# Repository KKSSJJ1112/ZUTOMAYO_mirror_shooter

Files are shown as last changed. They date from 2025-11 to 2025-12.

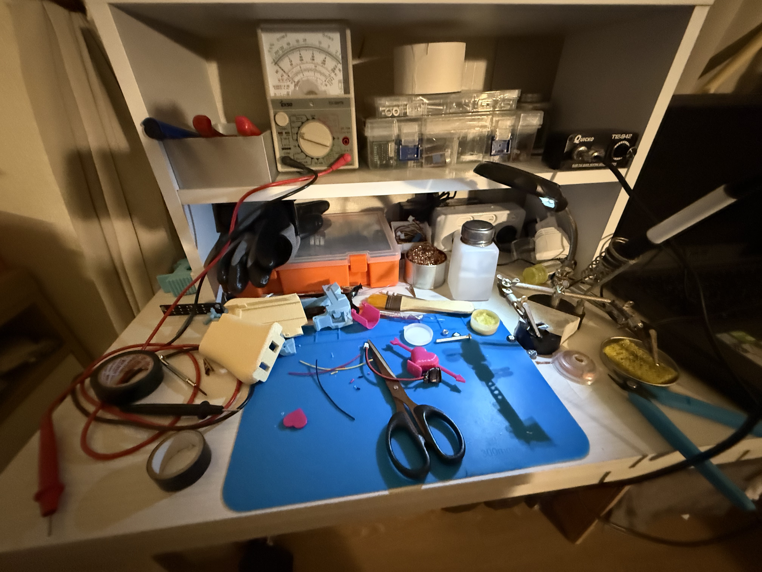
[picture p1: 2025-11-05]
사진/14.jpg

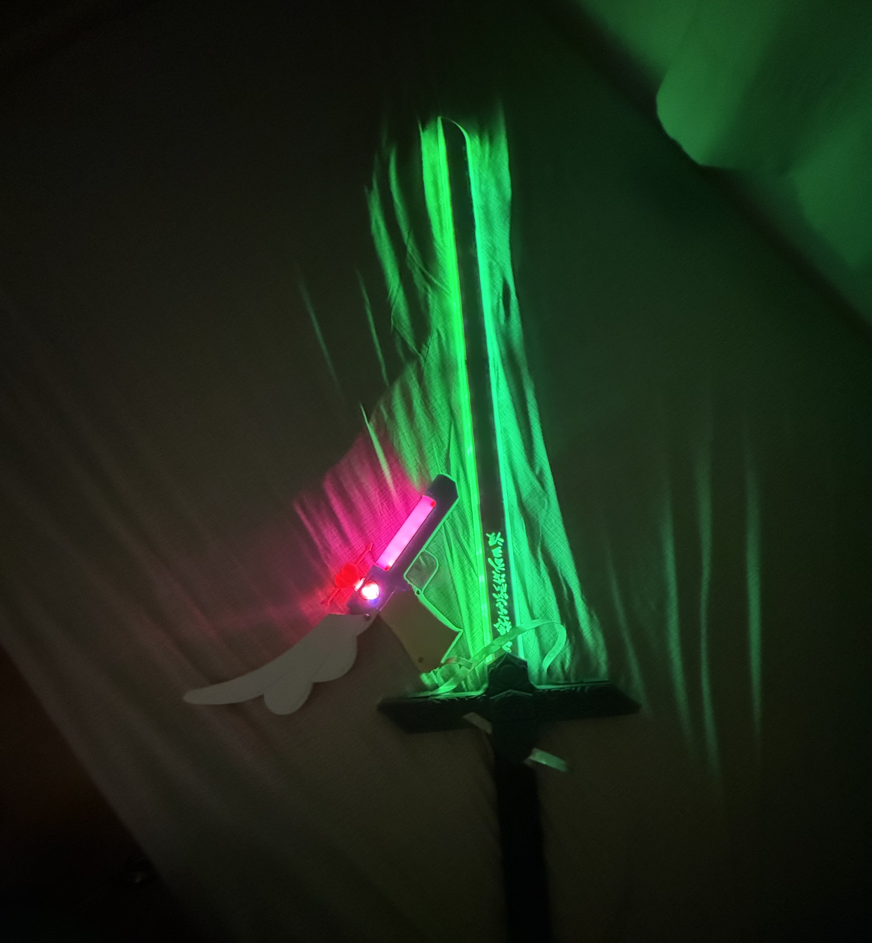
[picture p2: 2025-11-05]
사진/15.jpg

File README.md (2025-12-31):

ffa

# 🔫 Mirror Shooter / ミラーシューター / 미러슈터

> **Language / 言語 / 언어**: [English](#english) | [日本語](#日本語) | [한국어](#한국어)

---

## English

### ZUTOMAYO Mirror Shooter (DIY Replica)

A handmade replica of the mirror shooter prop featured in music videos and live performances by the Japanese J-pop band **ZUTOMAYO** (ずっと真夜中でいいのに。).

This pistol-shaped prop features LED illumination and a laser emitter at the muzzle.

### Features

- 3300mAh lithium-ion battery system
- Modular case design (assembly/disassembly capable)
- 3D printed enclosure
- Reprogrammable (color customization, etc.)
- Physical trigger switch for laser on/off mode toggle

### Components

| Part | Specification |
|---|---|
| PCB | Custom designed in KiCad, hand-soldered |
| MCU | ESP32-C3 Super Mini |
| LED Strip | NeoPixel (WS2812B) |
| Slide LED Ring | NeoPixel |
| Battery | Samsung SDI 18650 Li-ion cell |

### Project Structure

```
├── mirror/              # ESP32 PlatformIO project files
├── mirror_Shooter_v2/   # KiCad project files
└── mirrorshooter_stl/   # 3D printable STL files
```

### [Photos ↓](#gallery)

---

## 日本語

### ずっと真夜中でいいのに。ミラーシューター（自作レプリカ）

日本のJ-popバンド「**ずっと真夜中でいいのに。**」（以下、ずとまよ）のMVやライブに登場するミラーシューターを自作しました。

拳銃型の小道具で、LEDによる発光と銃口部分からのレーザー照射が特徴です。

### 主な特徴

- 3300mAhリチウムイオンバッテリーシステム
- 組み立て・分解可能なケース構造
- 3Dプリント製ケース
- 再プログラミング可能（カラー変更など）
- トリガーの物理プッシュスイッチによるレーザーON/OFFモード切替

### 構成部品

| 部品 | 仕様 |
|---|---|
| PCB | KiCadで設計、手はんだ実装 |
| MCU | ESP32-C3 Super Mini |
| LEDストリップ | NeoPixel（WS2812B） |
| スライド背面LEDリング | NeoPixel |
| バッテリー | Samsung SDI 18650 リチウムイオンセル |

### プロジェクト構成

```
├── mirror/              # ESP32 PlatformIOプロジェクトファイル
├── mirror_Shooter_v2/   # KiCadプロジェクトファイル
└── mirrorshooter_stl/   # 3Dプリント用STLファイル
```

### [写真 ↓](#gallery)

---

## 한국어

### 계속 한밤중이면 좋을텐데 미러슈터 (자작)

일본의 J-pop 밴드 **계속 한밤중이면 좋을텐데**(ずっと真夜中でいいのに。, 이하 즈토마요)의 MV 및 라이브에 등장하는 미러슈터를 제작했습니다.

권총형 소품으로, LED를 통한 발광과 총구 부분에서의 레이저가 특징입니다.

### 주요 특징

- 3300mAh 리튬 이온 배터리 시스템
- 조립 및 분해 가능한 케이스 구조
- 3D 프린팅 케이스
- 추후 재프로그래밍 가능 (색상 변경 등)
- 트리거의 물리 푸시 스위치를 통한 레이저 ON/OFF 모드 변경

### 구성 부품

| 부품 | 사양 |
|---|---|
| PCB | KiCad 설계, 핸드 솔더링 |
| MCU | ESP32-C3 Super Mini |
| LED 스트립 | NeoPixel (WS2812B) |
| 슬라이드 후면 LED 링 | NeoPixel |
| 배터리 | Samsung SDI 18650 리튬이온 셀 |

### 프로젝트 구조

```
├── mirror/              # ESP32 PlatformIO 프로젝트 파일
├── mirror_Shooter_v2/   # KiCad 프로젝트 파일
└── mirrorshooter_stl/   # 3D 프린팅용 STL 파일
```

### [사진 ↓](#gallery)

---

## Gallery

KakaoTalk_20251231_225942691_01

KakaoTalk_20251231_225942691_02







KakaoTalk_20251231_225942691



<!-- 이미지를 여기에 추가하세요 / Add images here / 画像をここに追加 -->

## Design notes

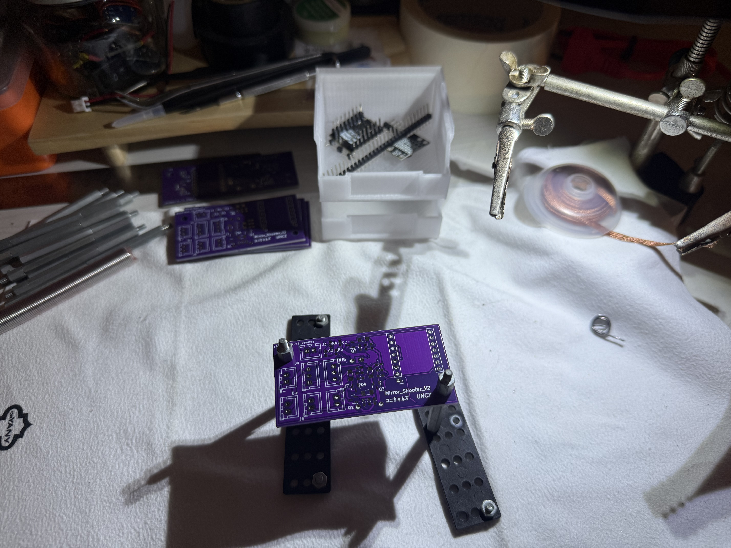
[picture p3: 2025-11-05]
사진/KakaoTalk_20250901_193324154_02.jpg

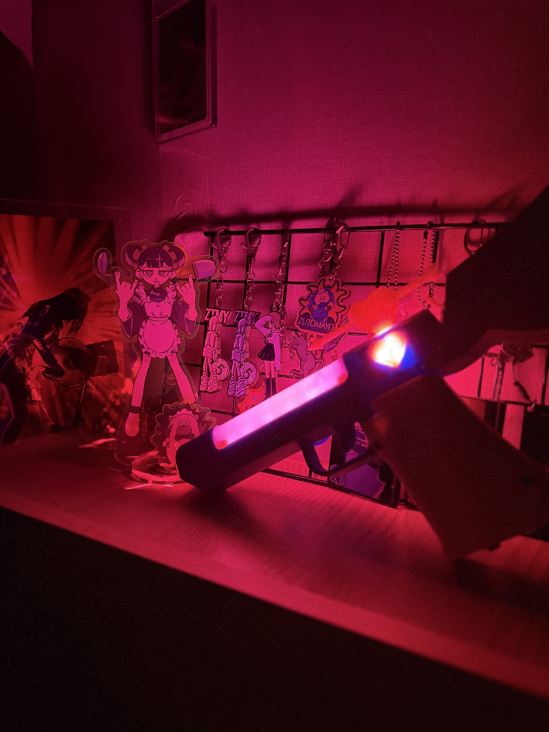
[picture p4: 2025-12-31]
사진/KakaoTalk_20251231_225942691_01.jpg

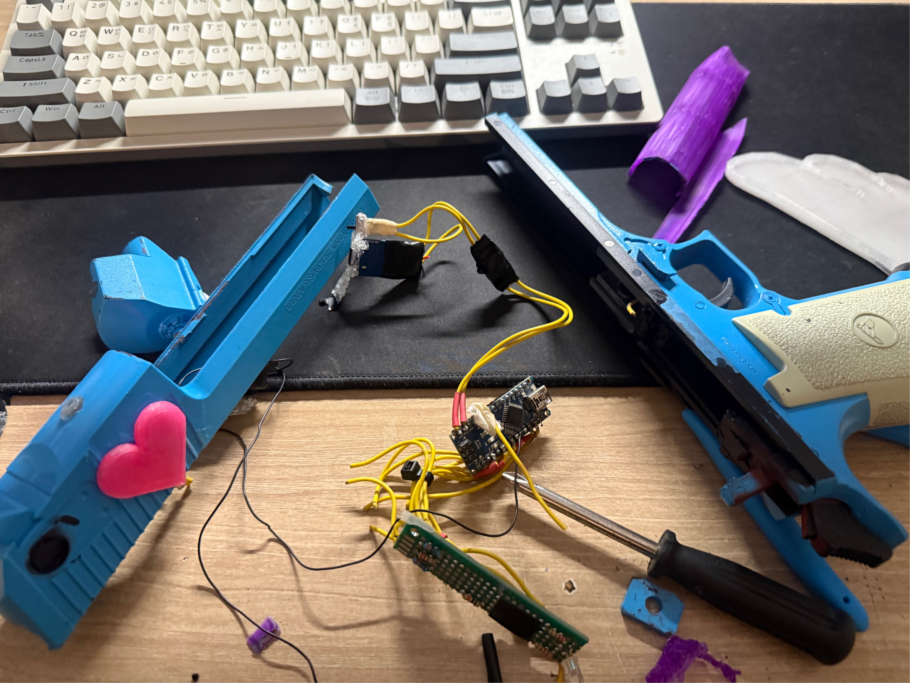
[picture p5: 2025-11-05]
사진/KakaoTalk_20250901_195342667_01.jpg

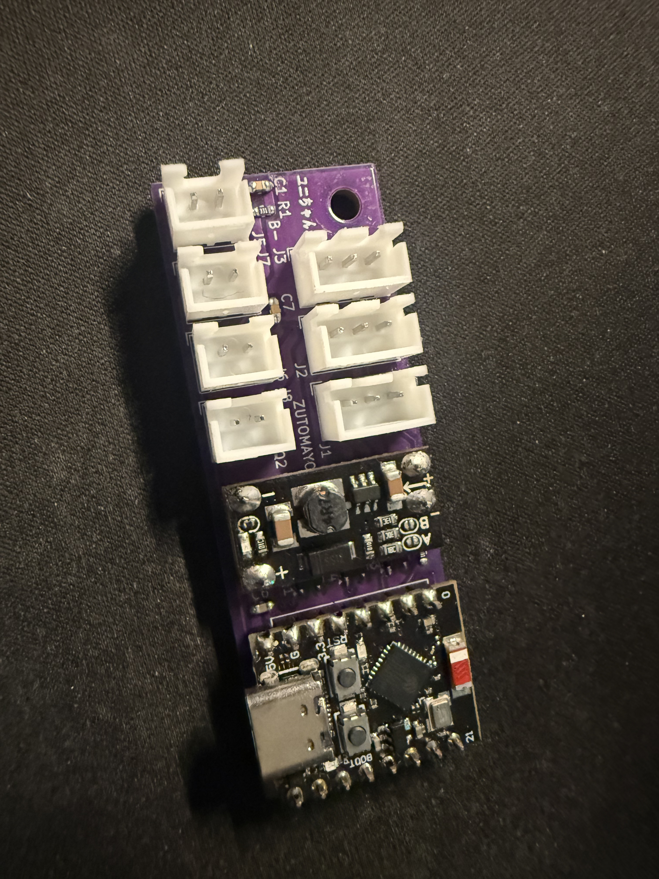
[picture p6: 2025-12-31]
사진/KakaoTalk_20251231_225942691.jpg

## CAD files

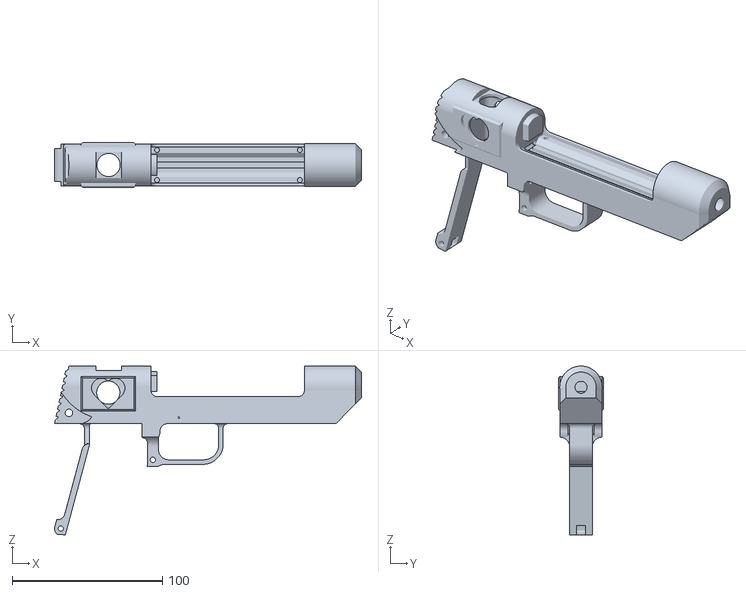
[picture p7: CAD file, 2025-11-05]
mirrorshooter_stl/____final/blue/main-frame.stl
204.2 x 30.0 x 112.3

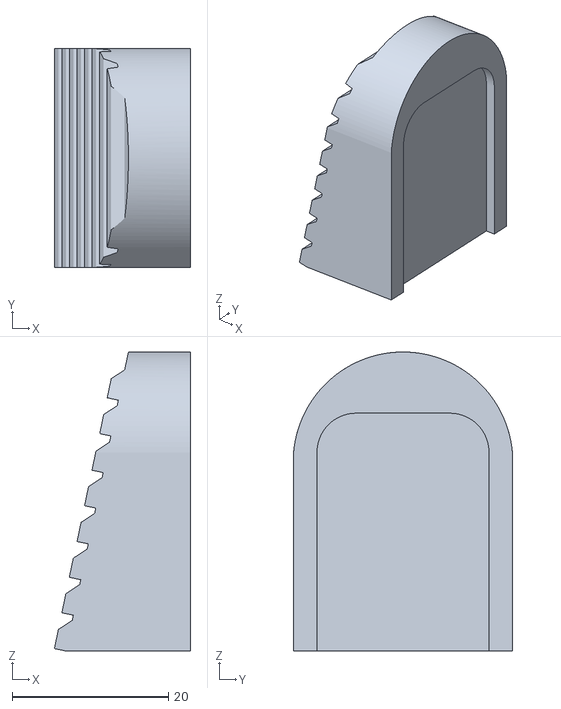
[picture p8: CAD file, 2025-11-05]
mirrorshooter_stl/test/first_test/ex_test/backside-main-test.stl
17.4 x 28.0 x 38.2

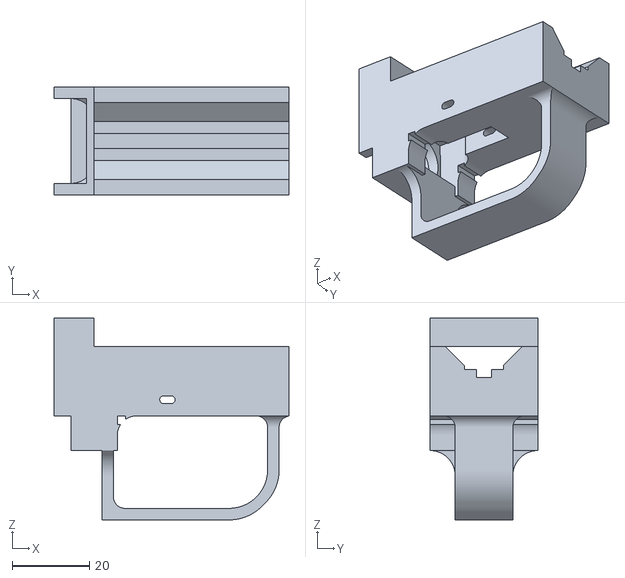
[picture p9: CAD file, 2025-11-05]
mirrorshooter_stl/test/first_test/trigger_test/triger-main-test.stl
61.0 x 28.0 x 52.4

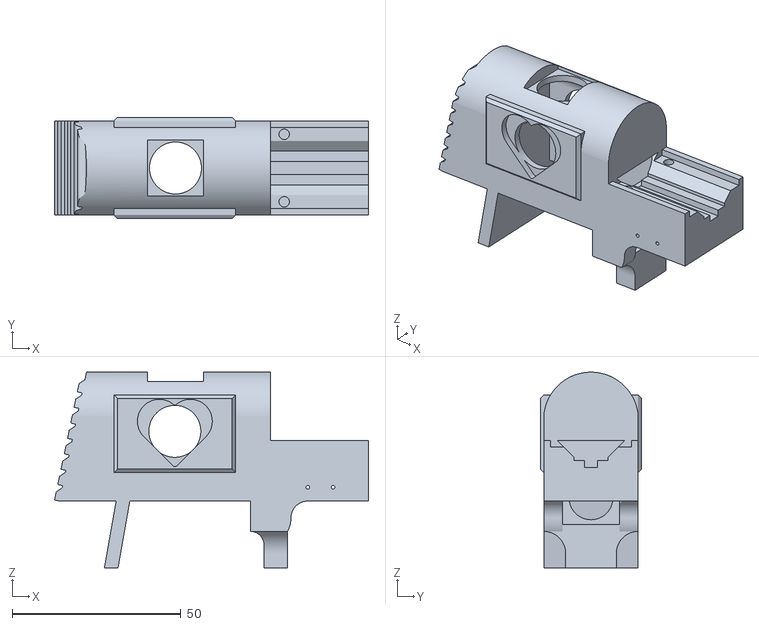
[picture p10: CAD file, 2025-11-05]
mirrorshooter_stl/test/second_test/blue/main frame test.stl
93.1 x 30.0 x 58.1

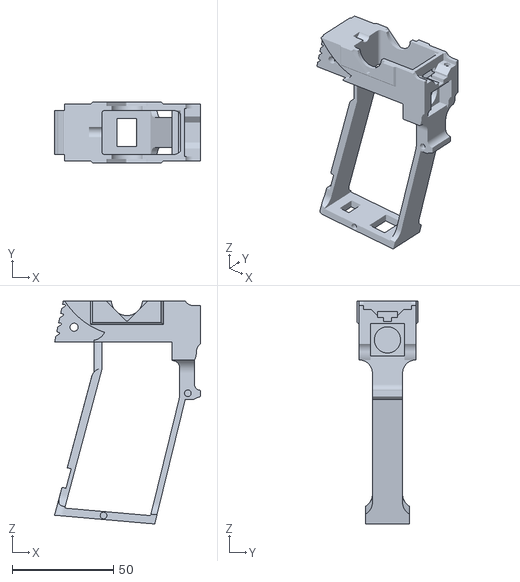
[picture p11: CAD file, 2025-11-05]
mirrorshooter_stl/test/second_test/blue/wing grip test main.stl
72.3 x 30.0 x 110.4

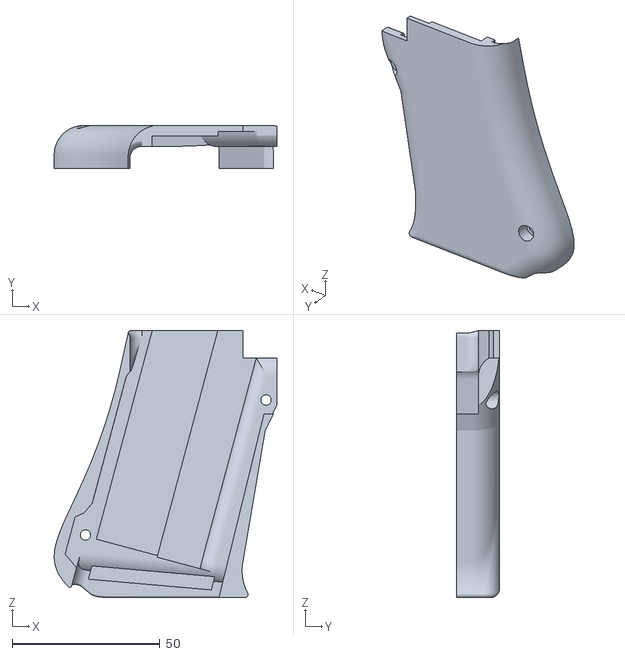
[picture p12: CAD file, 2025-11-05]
mirrorshooter_stl/____final/milk white/grib-l.stl
75.5 x 14.6 x 90.5

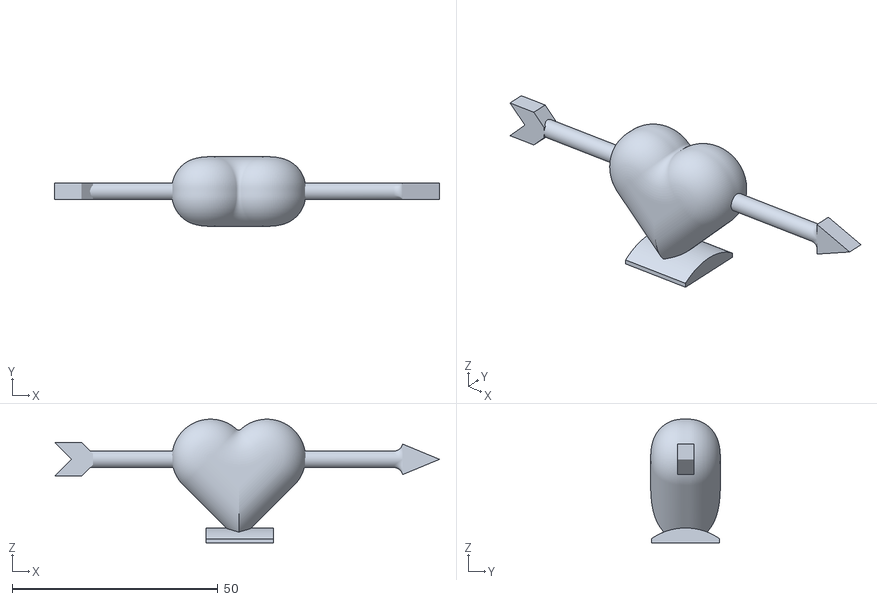
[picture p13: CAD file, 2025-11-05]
mirrorshooter_stl/____final/trans pink/big heart.stl
93.6 x 16.9 x 30.1

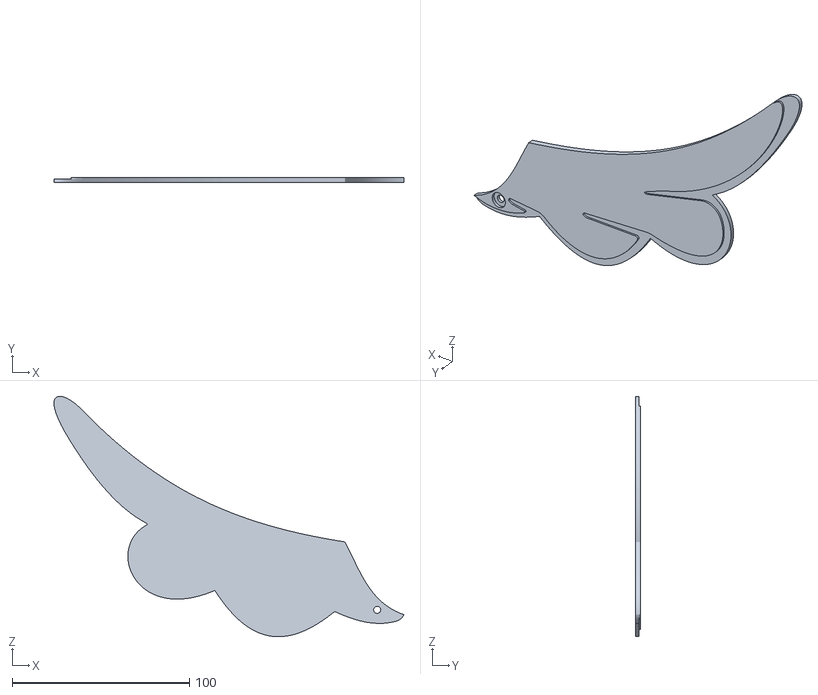
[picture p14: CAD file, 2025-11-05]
mirrorshooter_stl/____final/wing.stl
197.3 x 3.00 x 135.5

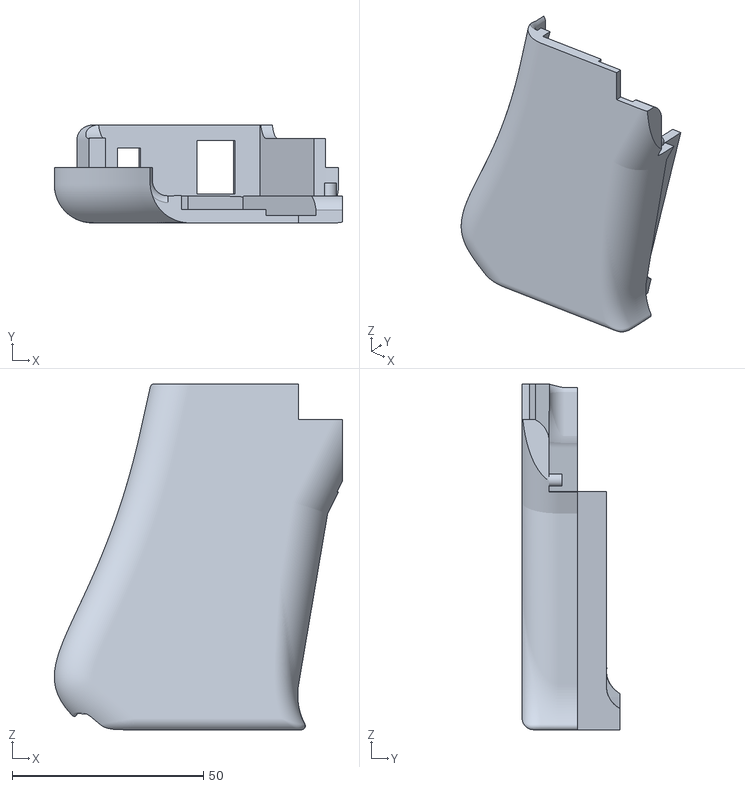
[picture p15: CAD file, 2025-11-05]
mirrorshooter_stl/test/3rd_test/grib-rr.stl
75.5 x 25.6 x 90.6

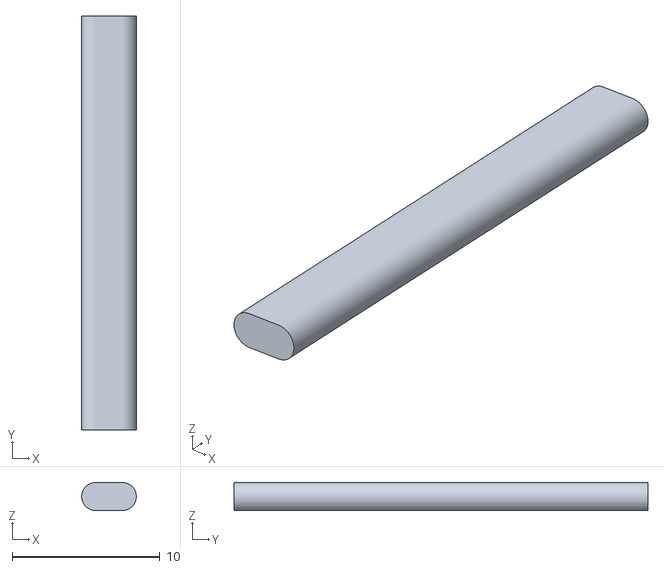
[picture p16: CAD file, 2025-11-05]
mirrorshooter_stl/test/first_test/trigger_test/triger-sub-bar.stl
3.70 x 28.0 x 1.90

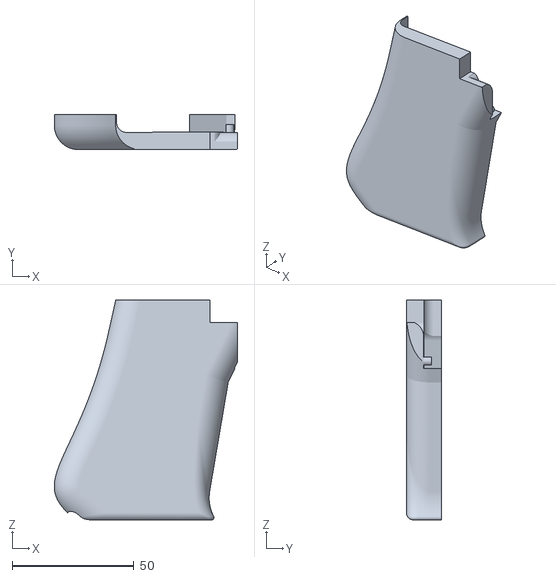
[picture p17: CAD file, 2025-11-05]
mirrorshooter_stl/test/second_test/bg/grip test 1.stl
75.5 x 14.5 x 90.5

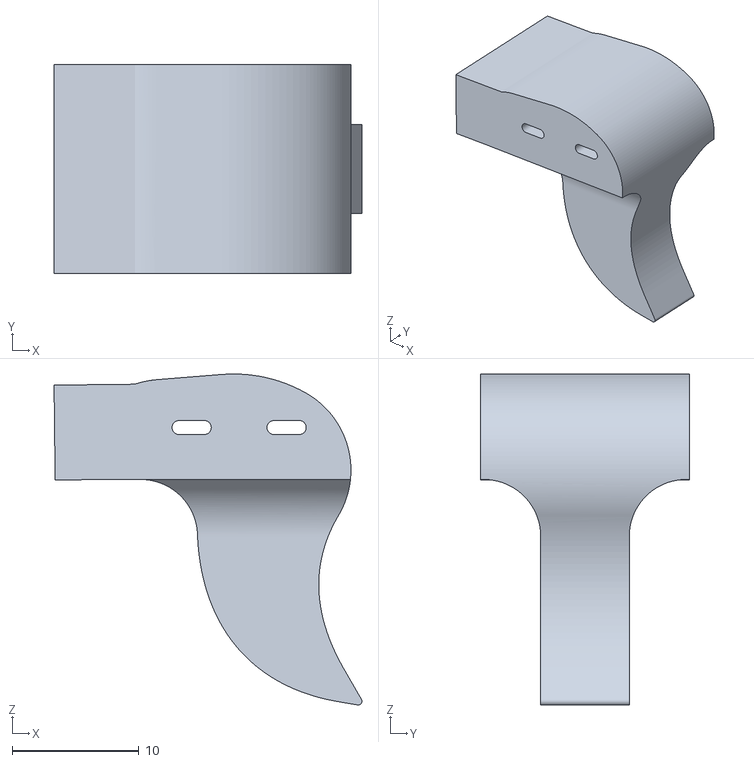
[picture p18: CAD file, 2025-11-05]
mirrorshooter_stl/test/second_test/blue/trigger test 3.stl
24.3 x 16.5 x 26.2

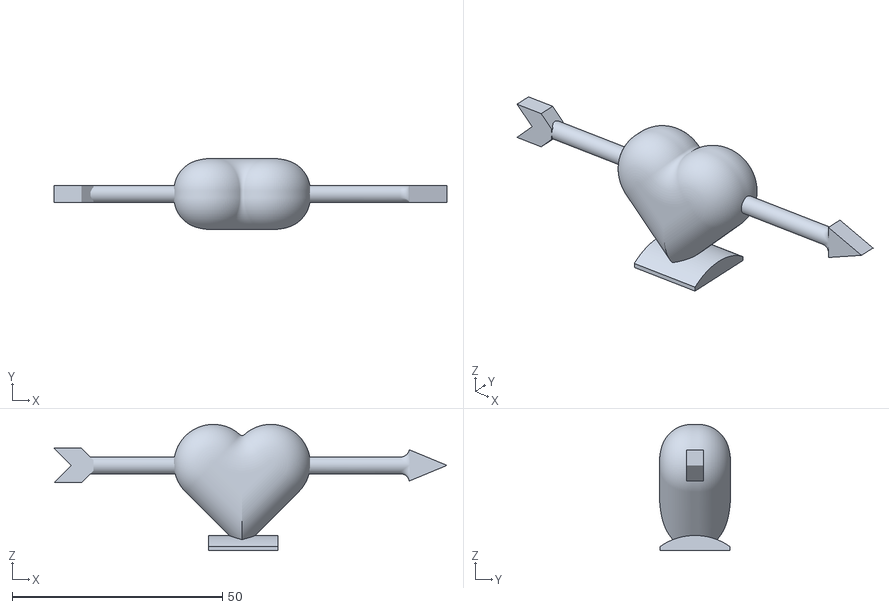
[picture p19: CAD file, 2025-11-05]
mirrorshooter_stl/test/second_test/trans_pink/big heart hest.stl
93.6 x 16.9 x 30.1

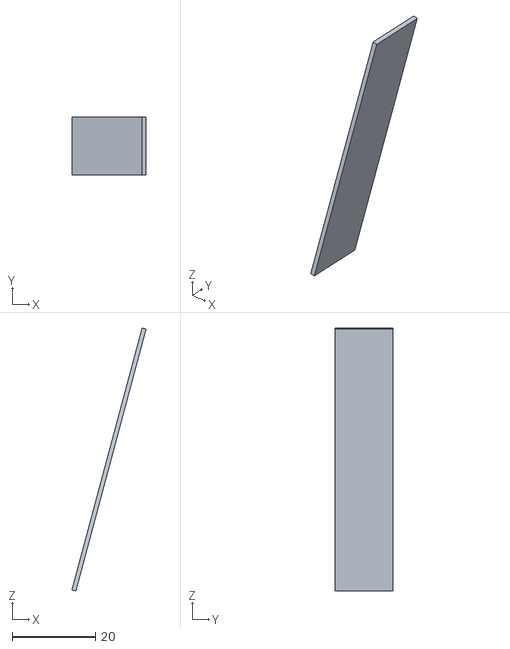
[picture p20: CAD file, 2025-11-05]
mirrorshooter_stl/test/test4/plate.stl
17.8 x 14.0 x 63.0

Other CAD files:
mirrorshooter_stl/test/3rd_test/main-frame.stl
mirrorshooter_stl/test/second_test/white/wing test 1.stl
mirrorshooter_stl/____final/blue/ring holder.stl
mirrorshooter_stl/____final/milk white/grib-r.stl
mirrorshooter_stl/____final/blue/trigger.stl
mirrorshooter_stl/____final/trans pink/cover.stl
mirrorshooter_stl/____final/trans pink/small heart.stl
mirrorshooter_stl/test/3rd_test/grib-ll.stl
mirrorshooter_stl/test/3rd_test/grib-lll.stl
mirrorshooter_stl/test/3rd_test/grib-rrr.stl
mirrorshooter_stl/test/first_test/trigger_test/triger-sub-invisible.stl
mirrorshooter_stl/test/first_test/trigger_test/triger-triger.stl
mirrorshooter_stl/test/second_test/blue/holder5.stl
mirrorshooter_stl/test/second_test/blue/ring holder 4.stl
mirrorshooter_stl/test/second_test/blue/ring holder ttesst.stl
mirrorshooter_stl/test/second_test/blue/trigger test 4.stl
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

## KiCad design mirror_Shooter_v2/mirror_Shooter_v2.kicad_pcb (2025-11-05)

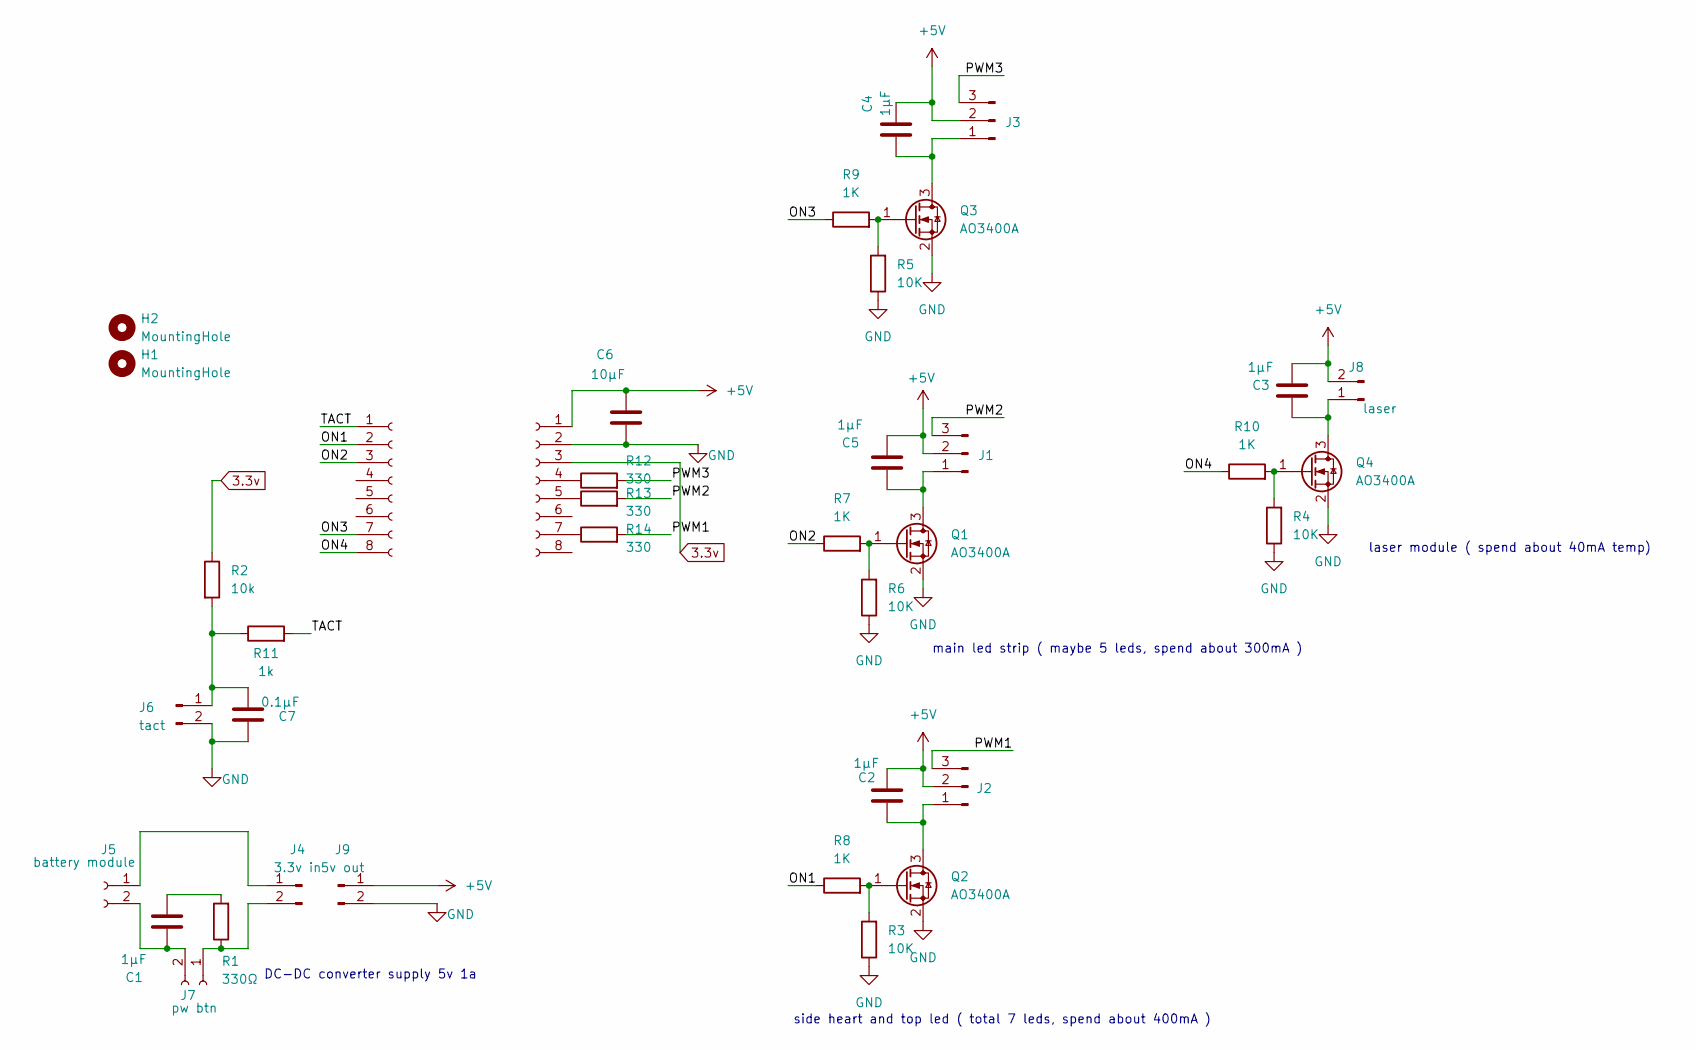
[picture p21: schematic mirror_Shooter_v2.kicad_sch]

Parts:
C1, C2, C3, C4, C5: 1μF; C_0603_1608Metric_Pad1.08x0.95mm_HandSolder
C6: 10μF; C_0603_1608Metric_Pad1.08x0.95mm_HandSolder
C7: 0.1μF; C_0603_1608Metric_Pad1.08x0.95mm_HandSolder
H1, H2: MountingHole; MountingHole_3.2mm_M3
J1, J2, J3: Conn_01x03_Pin; JST_XH_B3B-XH-A_1x03_P2.50mm_Vertical
J4: 3.3v in; 제목 없음
J5: battery module; JST_XH_B2B-XH-A_1x02_P2.50mm_Vertical
J6: tact; JST_XH_B2B-XH-A_1x02_P2.50mm_Vertical
J7: pw btn; JST_XH_B2B-XH-A_1x02_P2.50mm_Vertical
J8: laser; JST_XH_B2B-XH-A_1x02_P2.50mm_Vertical
J9: 5v out; stepup in
J10, J11: Conn_01x08_Socket; PinHeader_1x08_P2.54mm_Vertical
Q1, Q2, Q3, Q4: AO3400A; SOT-23
R1: 330Ω; C_0603_1608Metric_Pad1.08x0.95mm_HandSolder
R2: 10k; C_0603_1608Metric_Pad1.08x0.95mm_HandSolder
R3, R4, R5, R6: 10K; C_0603_1608Metric_Pad1.08x0.95mm_HandSolder
R7, R8, R9, R10: 1K; C_0603_1608Metric_Pad1.08x0.95mm_HandSolder
R11: 1k; C_0603_1608Metric_Pad1.08x0.95mm_HandSolder
R12, R13, R14: 330; C_0603_1608Metric_Pad1.08x0.95mm_HandSolder

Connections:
3.3v: J10.3, R2.1
+5V: C2.1, C3.1, C4.1, C5.1, C6.1, J1.2, J2.2, J3.2, J8.2, J9.1, J10.1
/ON1: J11.2, R8.1
/ON2: J11.3, R7.1
/ON3: J11.7, R9.1
/ON4: J11.8, R10.1
/PWM1: J2.3, R14.2
/PWM2: J1.3, R13.2
/PWM3: J3.3, R12.2
/TACT: J11.1, R11.2
GND: C6.2, C7.2, J6.2, J9.2, J10.2, Q1.2 (S), Q2.2 (S), Q3.2 (S), Q4.2 (S), R3.1, R4.1, R5.1, R6.1
unnamed: C1.2, R1.2
unnamed: C5.2, J1.1, Q1.3 (D)
unnamed: C2.2, J2.1, Q2.3 (D)
unnamed: C4.2, J3.1, Q3.3 (D)
unnamed: J4.1, J5.1
unnamed: J4.2, J7.1, R1.1
unnamed: C1.1, J5.2, J7.2
unnamed: C7.1, J6.1, R2.2, R11.1
unnamed: C3.2, J8.1, Q4.3 (D)
unnamed: J10.4, R12.1
unnamed: J10.5, R13.1
unnamed: J10.7, R14.1
unnamed: Q1.1 (G), R6.2, R7.2
unnamed: Q2.1 (G), R3.2, R8.2
unnamed: Q3.1 (G), R5.2, R9.2
unnamed: Q4.1 (G), R4.2, R10.2

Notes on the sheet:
DC-DC converter supply 5v 1a
main led strip ( maybe 5 leds, spend about 300mA )
laser module ( spend about 40mA temp)
side heart and top led ( total 7 leds, spend about 400mA )

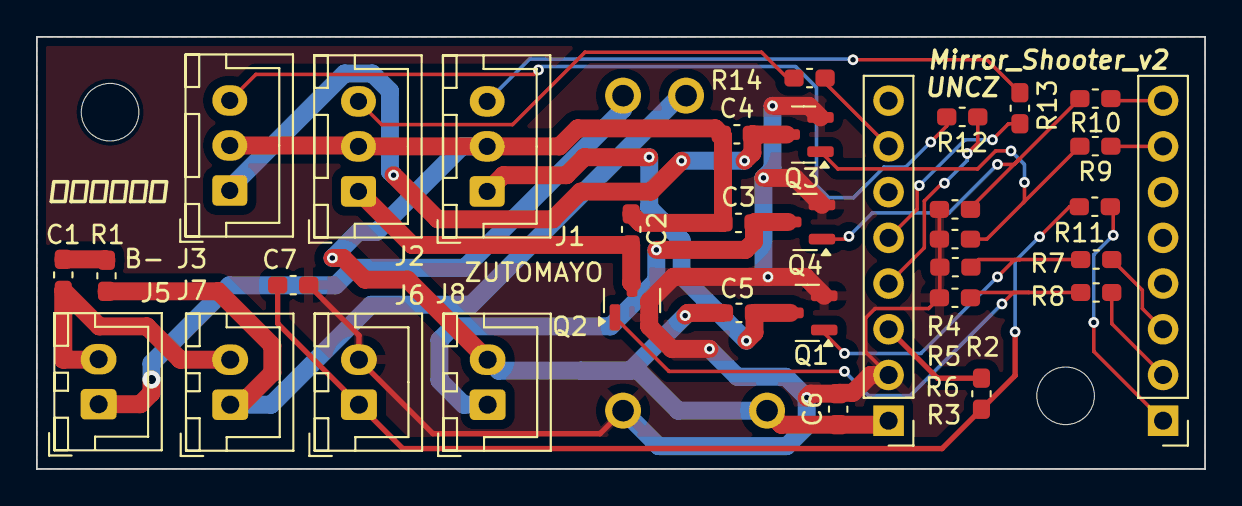
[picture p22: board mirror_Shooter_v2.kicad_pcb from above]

Board: 2 copper layers, 64.9 x 24.0 mm, 38 parts (0 on the bottom side), 27 nets.

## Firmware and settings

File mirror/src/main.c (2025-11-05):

#include <stdio.h>
#include "driver/gpio.h"
#include "freertos/FreeRTOS.h"
#include "freertos/task.h"
#include "freertos/queue.h"
#include "esp_log.h"
#include "ws2812.h"

#define STRIP_LED_NUM 6
#define STRIP_GPIO 4
#define STRIP_POWER 20

#define TRI_LED_NUM 9
#define TRI_GPIO 3
#define TRI_POWER 7

#define BUTTON_GPIO 5

#define LASER_POWER 21


static const char *TAG = "LOGGG";

static void button_task(void* arg){
    int led_state = 0;
    int last_button_state = 1;  // 풀업이므로 기본 HIGH

    while(1){
        int current_state = gpio_get_level(BUTTON_GPIO);
        
        // 변화 감지 (HIGH→LOW)`
        if(last_button_state == 1 && current_state == 0){
            
            // 디바운싱: 20ms 후 재확인
            vTaskDelay(pdMS_TO_TICKS(20));
            
            // 여전히 눌려있는지 확인
            if(gpio_get_level(BUTTON_GPIO) == 0){
                
                led_state = !led_state;
                gpio_set_level(LASER_POWER, led_state);
                
            }
        }
        
        last_button_state = current_state;
        vTaskDelay(pdMS_TO_TICKS(10));  // 10ms마다 체크
    }
}


void app_main(void)
{   

    vTaskDelay(pdMS_TO_TICKS(100));
    
    ESP_LOGI("MAIN", "=== Start ===");
    
    // GPIO 리셋부터
    gpio_reset_pin(LASER_POWER);
    gpio_reset_pin(STRIP_POWER);
    gpio_reset_pin(TRI_POWER);
    gpio_reset_pin(BUTTON_GPIO);

    ESP_LOGI(TAG,"LASER_POWER PIN %d", LASER_POWER);
    ESP_LOGI(TAG,"TRI_POWER PIN %d", TRI_POWER);
    ESP_LOGI(TAG,"STRIP_POWER PIN %d", STRIP_POWER);
    ESP_LOGI(TAG,"BTN PIN %d", BUTTON_GPIO);

    
    // 출력 설정
    gpio_set_direction(LASER_POWER, GPIO_MODE_OUTPUT);
    gpio_set_direction(STRIP_POWER, GPIO_MODE_OUTPUT);
    gpio_set_direction(TRI_POWER, GPIO_MODE_OUTPUT);
    
    // 명확히 LOW로
    gpio_set_level(LASER_POWER, 0);
    gpio_set_level(STRIP_POWER, 0);
    gpio_set_level(TRI_POWER, 0);



    neopixel_handle_t *strip = neoPixel_create(STRIP_GPIO, STRIP_LED_NUM);
    neopixel_handle_t *tri = neoPixel_create(TRI_GPIO, TRI_LED_NUM);

    neoPixel_clear(strip, true);
    neoPixel_clear(tri, true);

    gpio_config_t io_conf = {
        .pin_bit_mask = (1ULL << BUTTON_GPIO),
        .mode = GPIO_MODE_INPUT,
        .pull_up_en = GPIO_PULLUP_DISABLE,
        .pull_down_en = GPIO_PULLDOWN_DISABLE,
        .intr_type = GPIO_INTR_DISABLE
    };

    gpio_config(&io_conf);

    xTaskCreate(button_task, "button", 2048, NULL, 10, NULL);


    gpio_set_level(STRIP_POWER, 1);
    gpio_set_level(TRI_POWER, 1);
    gpio_set_level(LASER_POWER, 0);

    while(1){

        for(int i =0; i<STRIP_LED_NUM; i++){
            neoPixel_set_pixel(strip, i, 170, 30 , 50);
        }
        
        neoPixel_display(strip);
       

        for(int i =0; i<TRI_LED_NUM; i++){
            neoPixel_set_pixel(tri, i, 170, 30 , 50);
        }

        neoPixel_display(tri);
   

    }


}

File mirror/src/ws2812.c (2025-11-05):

#include "ws2812.h"
#include "driver/rmt_tx.h"
#include "esp_log.h"
#include <string.h>
#include <stdlib.h>

static const char *TAG = "WS2812";




neopixel_handle_t *neoPixel_create(uint8_t gpio, uint8_t num_leds){

    neopixel_handle_t *handle = (neopixel_handle_t*)malloc(sizeof(neopixel_handle_t));
    if(handle == NULL){
        ESP_LOGE(TAG, "failed allocate memory");
        return NULL;
    }

    handle->num_pixel = num_leds;
    handle->gpio = gpio;

    handle->pixel_data = (uint8_t*)calloc(num_leds * 3, sizeof(uint8_t));
    if(handle->pixel_data == NULL){
        ESP_LOGE(TAG, "pixel data allocate failed");
        free(handle);
        return NULL;
    }    // RMT 채널 설정
    rmt_tx_channel_config_t tx_config = {
        .gpio_num = gpio,
        .clk_src = RMT_CLK_SRC_DEFAULT,
        .resolution_hz = 10000000,
        .mem_block_symbols = 48,
        .trans_queue_depth = 1,
    };



    
    esp_err_t ret = rmt_new_tx_channel(&tx_config, &handle->rmt_channel);
    if (ret != ESP_OK) {
        ESP_LOGE(TAG, "RMT 채널 생성 실패");
        free(handle->pixel_data);
        free(handle);
        return NULL;
    }
    
    // 바이트 인코더 설정
    rmt_bytes_encoder_config_t encoder_config = {
        .bit0 = {
            .level0 = 1,
            .duration0 = 3,
            .level1 = 0,
            .duration1 = 9,
        },
        .bit1 = {
            .level0 = 1,
            .duration0 = 9,
            .level1 = 0,
            .duration1 = 3,
        },
        .flags.msb_first = 1
    };
    
    ret = rmt_new_bytes_encoder(&encoder_config, &handle->encoder);
    if (ret != ESP_OK) {
        ESP_LOGE(TAG, "인코더 생성 실패");
        rmt_del_channel(handle->rmt_channel);
        free(handle->pixel_data);
        free(handle);
        return NULL;
    }
    
    // RMT 채널 활성화
    ret = rmt_enable(handle->rmt_channel);
    if (ret != ESP_OK) {
        ESP_LOGE(TAG, "RMT 활성화 실패");
        return NULL;
    }
    
    ESP_LOGI(TAG, "네오픽셀 생성: GPIO %d, %d LEDs", gpio, num_leds);
    return handle;


}




void neoPixel_set_pixel(neopixel_handle_t* handle, uint8_t index, uint8_t R, uint8_t G, uint8_t B){

    if (handle == NULL || index >= handle->num_pixel) {
        return;
    }
    
    // GRB 순서로 저장
    handle->pixel_data[index * 3 + 0] = G;
    handle->pixel_data[index * 3 + 1] = R;
    handle->pixel_data[index * 3 + 2] = B;

}




void neoPixel_display(neopixel_handle_t *handle){

    if (handle == NULL) return;

    rmt_transmit_config_t tx_config = {
        .loop_count =0,
    };

    esp_err_t ret = rmt_transmit(
        handle->rmt_channel,
        handle->encoder,
        handle->pixel_data,
        handle->num_pixel * 3,
        &tx_config
    );

    if(ret != ESP_OK){
        ESP_LOGE(TAG, "tx failed");
        return;
    }

    rmt_tx_wait_all_done(handle->rmt_channel, 50);

}



void neoPixel_clear(neopixel_handle_t *handle, bool mode){

    if (handle == NULL) return;

    memset(handle->pixel_data, 0, handle->num_pixel*3);

    if(mode){
        neoPixel_display(handle);
    }

}




void neoPixel_destroy(neopixel_handle_t *handle){

    if(handle==NULL) return;

    rmt_disable(handle->rmt_channel);
    rmt_del_encoder(handle->encoder);
    rmt_del_channel(handle->rmt_channel);
    free(handle->pixel_data);
    free(handle);
}
